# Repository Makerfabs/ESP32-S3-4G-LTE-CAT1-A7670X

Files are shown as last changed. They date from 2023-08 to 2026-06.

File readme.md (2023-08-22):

# ESP32-S3-Parallel-TFT-with-Touch-1.9inch

```
/* 
    Version:      V1.0
    Author:       Vincent
    Create Date:  2023/8/22
*/
```

# Makerfabs

[Makerfabs home page](https://www.makerfabs.com/)

[Makerfabs Wiki](https://wiki.makerfabs.com/)

## Intruduce

Product Link:[]()

Wiki Link : []()

## Features

- Controller: ESP32-S3
- Wireless: WiFi& Bluetooth 5.0
- Arduino support
- MicroPython support: Yes
- Operation temperature: -40℃ to +85℃
- USB: USB Native, Type-C
- Power Supply: USB Type-C 5.0V(4.0V~5.25V); 3.7V Lipo battery

# Usage

All supporting information, such as the AT instructions and other official documents are in the A76XX Manual.zip.

## Complier Option

- Use type-c use cable connect USB-TTL to PC.
- Select "ESP32-S3 DEV Module"
- Select PSRAM "OPI PSRAM"

## Example

at_command_demo.ino

Serial port transparent transmission demo.
Can be used to test AT Commands.

## AT Commands

### AT+CSQ

Query signal quality

```
AT+CSQ
+CSQ: 28,99

OK

```

### AT+SIMCOMATI

Example Query module information

```
AT+SIMCOMATI
Manufacturer: INCORPORATED
Model: A7670SA-FASE
Revision: A011B04A7670M7_F
A7670M7_B04V02_220927
QCN:
IMEI: 869731059057646
MEID:
+GCAP: +CGSM,+FCLASS,+DS
DeviceInfo:

OK

```

### AT+COPS

Operator selection

```
AT+COPS?
+COPS: 0,2,"46000",7

OK

```

### AT+CICCID

Read ICCID from SIM card

```
AT+CICCID
+ICCID: 898607E0102250030751

OK

```

### AT+CBC

Read the voltage value of the power supply

```
AT+CBC
+CBC: 4.167V

OK

```

## TTS Test

```
AT+CTTSPARAM=? 
AT+CTTSPARAM=1,3,0,1,1 
AT+CTTSPARAM?
AT+CTTS=1,"6B228FCE4F7F75288BED97F3540862107CFB7EDF" 
AT+CTTS=2,"Hi, Makerfabs"

```

## LBS Test

```
AT+CLBS=? 
AT+SIMCOMATI
AT+SIMEI=xxxxx 
AT+CLBS=2 
AT+CLBS=1
```

## Make a call

```
ATD<phone_number>;
AT+COUTGAIN=?
AT+COUTGAIN=5
AT+CHUP 
```
## TCP test

```
AT+CIPMODE=1
AT+NETOPEN
AT+CIPOPEN=0,"TCP","122.114.122.174",39348
Hi,Makerfabs
AT+CIPCLOSE=0
AT+NETCLOSE
```
## LBS Test

```
AT+CLBS=? 
AT+SIMCOMATI
AT+SIMEI=xxxxx 
AT+CLBS=2 
AT+CLBS=1
```
## HTTP Test

```
AT+HTTPINIT
AT+HTTPPARA="URL","http:www.makerfabs.com"
AT+HTTPACTION=0
AT+HTTPHEAD
AT+HTTPREAD=0,500
AT+HTTPTERM
```

## MQTT Test

```
AT+CMQTTSTART
AT+CMQTTACCQ=0,"client test0"
AT+CMQTTWILLTOPIC=0,10
AT+CMQTTWILLMSG=0,6,1
AT+CMQTTCONNECT=0,"tcp://test.mosquitto.org:1883",60,1
AT+CMQTTSUB=0,9,1
AT+CMQTTTOPIC=0,9
AT+CMQTTPAYLOAD=0,60
```

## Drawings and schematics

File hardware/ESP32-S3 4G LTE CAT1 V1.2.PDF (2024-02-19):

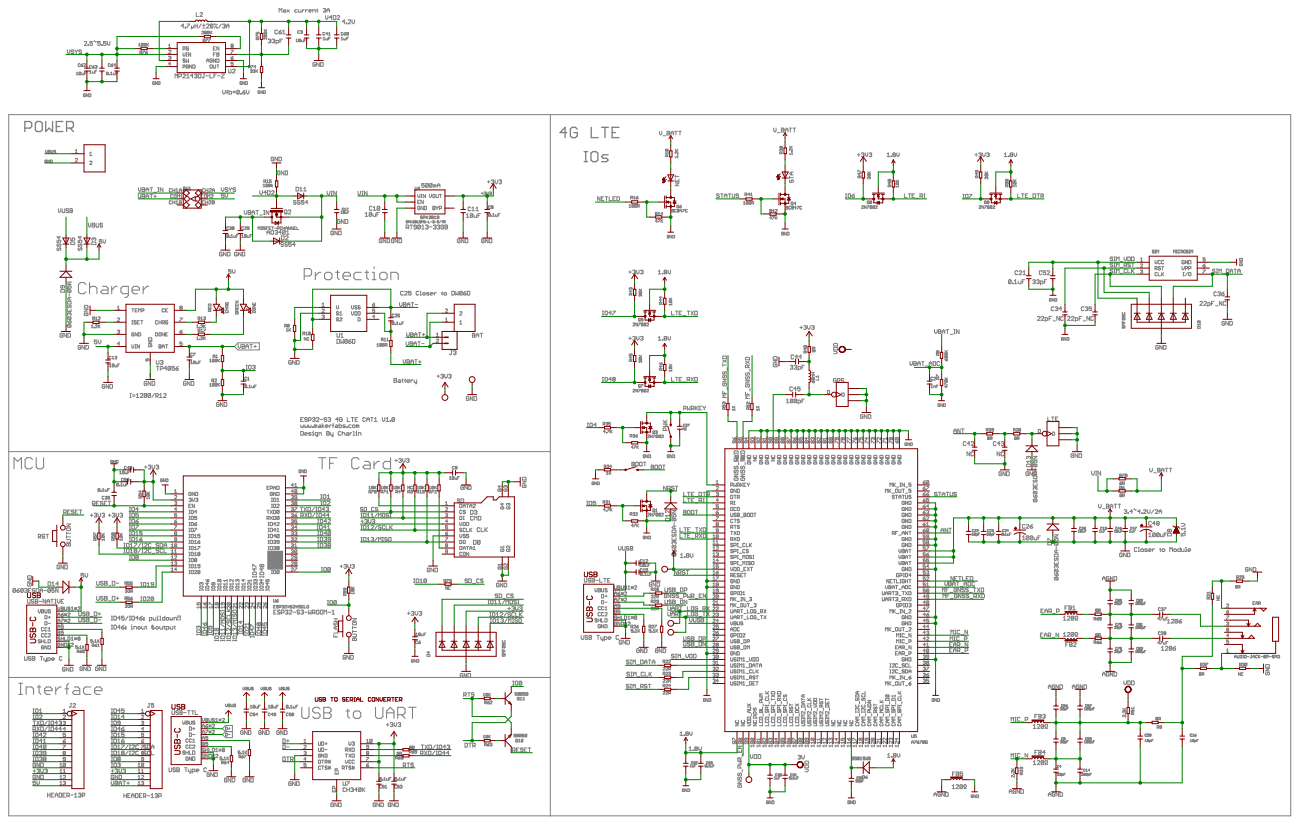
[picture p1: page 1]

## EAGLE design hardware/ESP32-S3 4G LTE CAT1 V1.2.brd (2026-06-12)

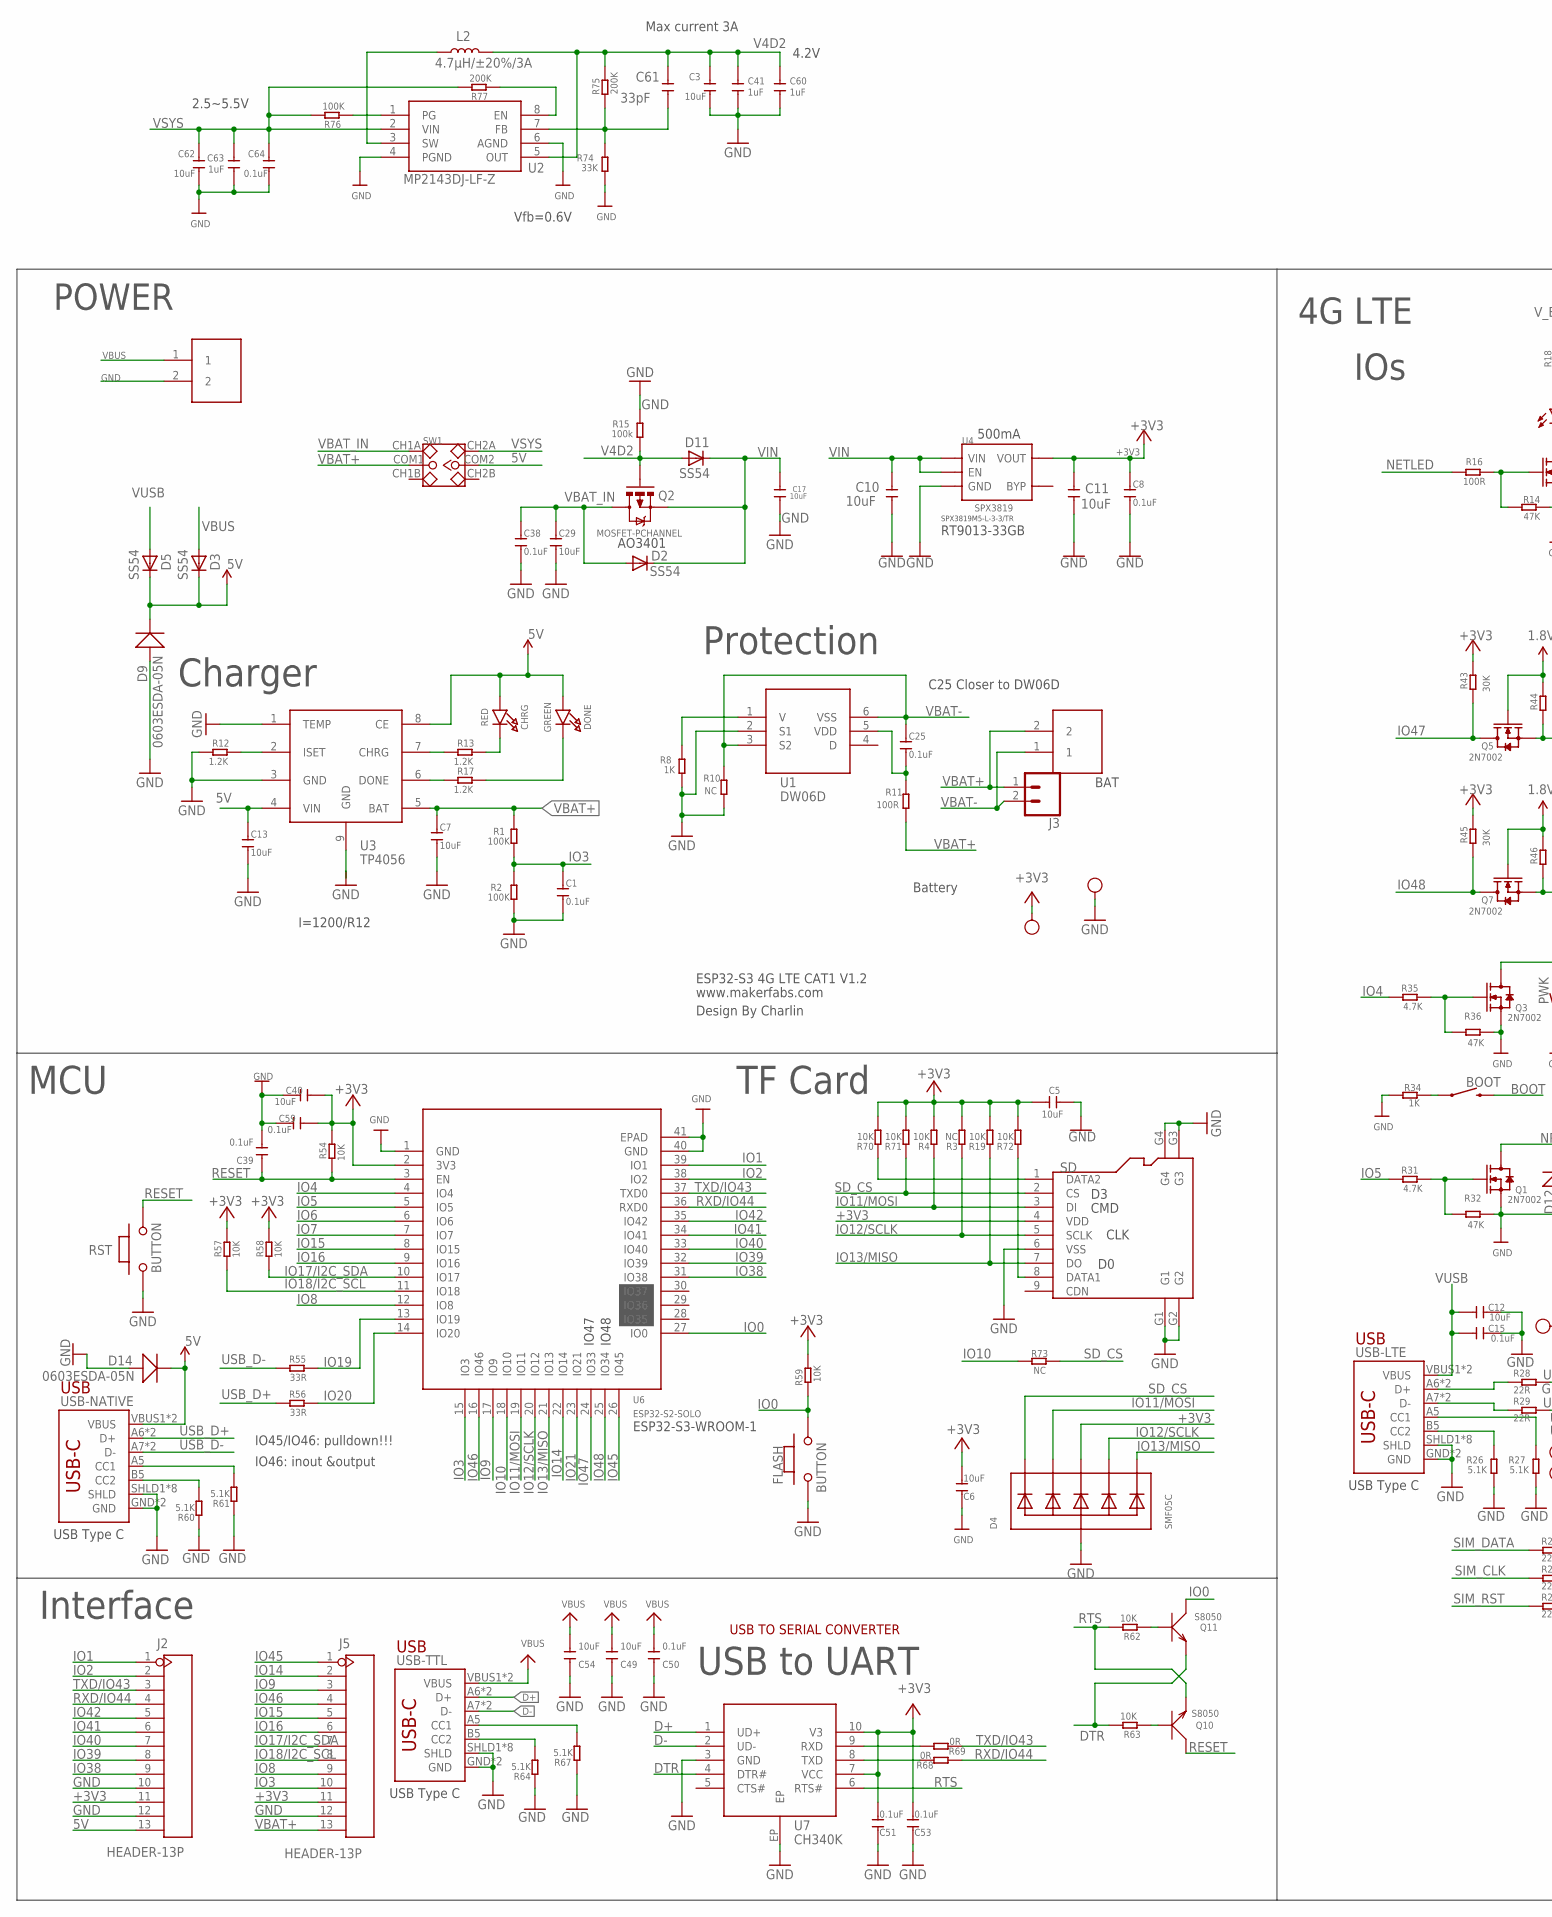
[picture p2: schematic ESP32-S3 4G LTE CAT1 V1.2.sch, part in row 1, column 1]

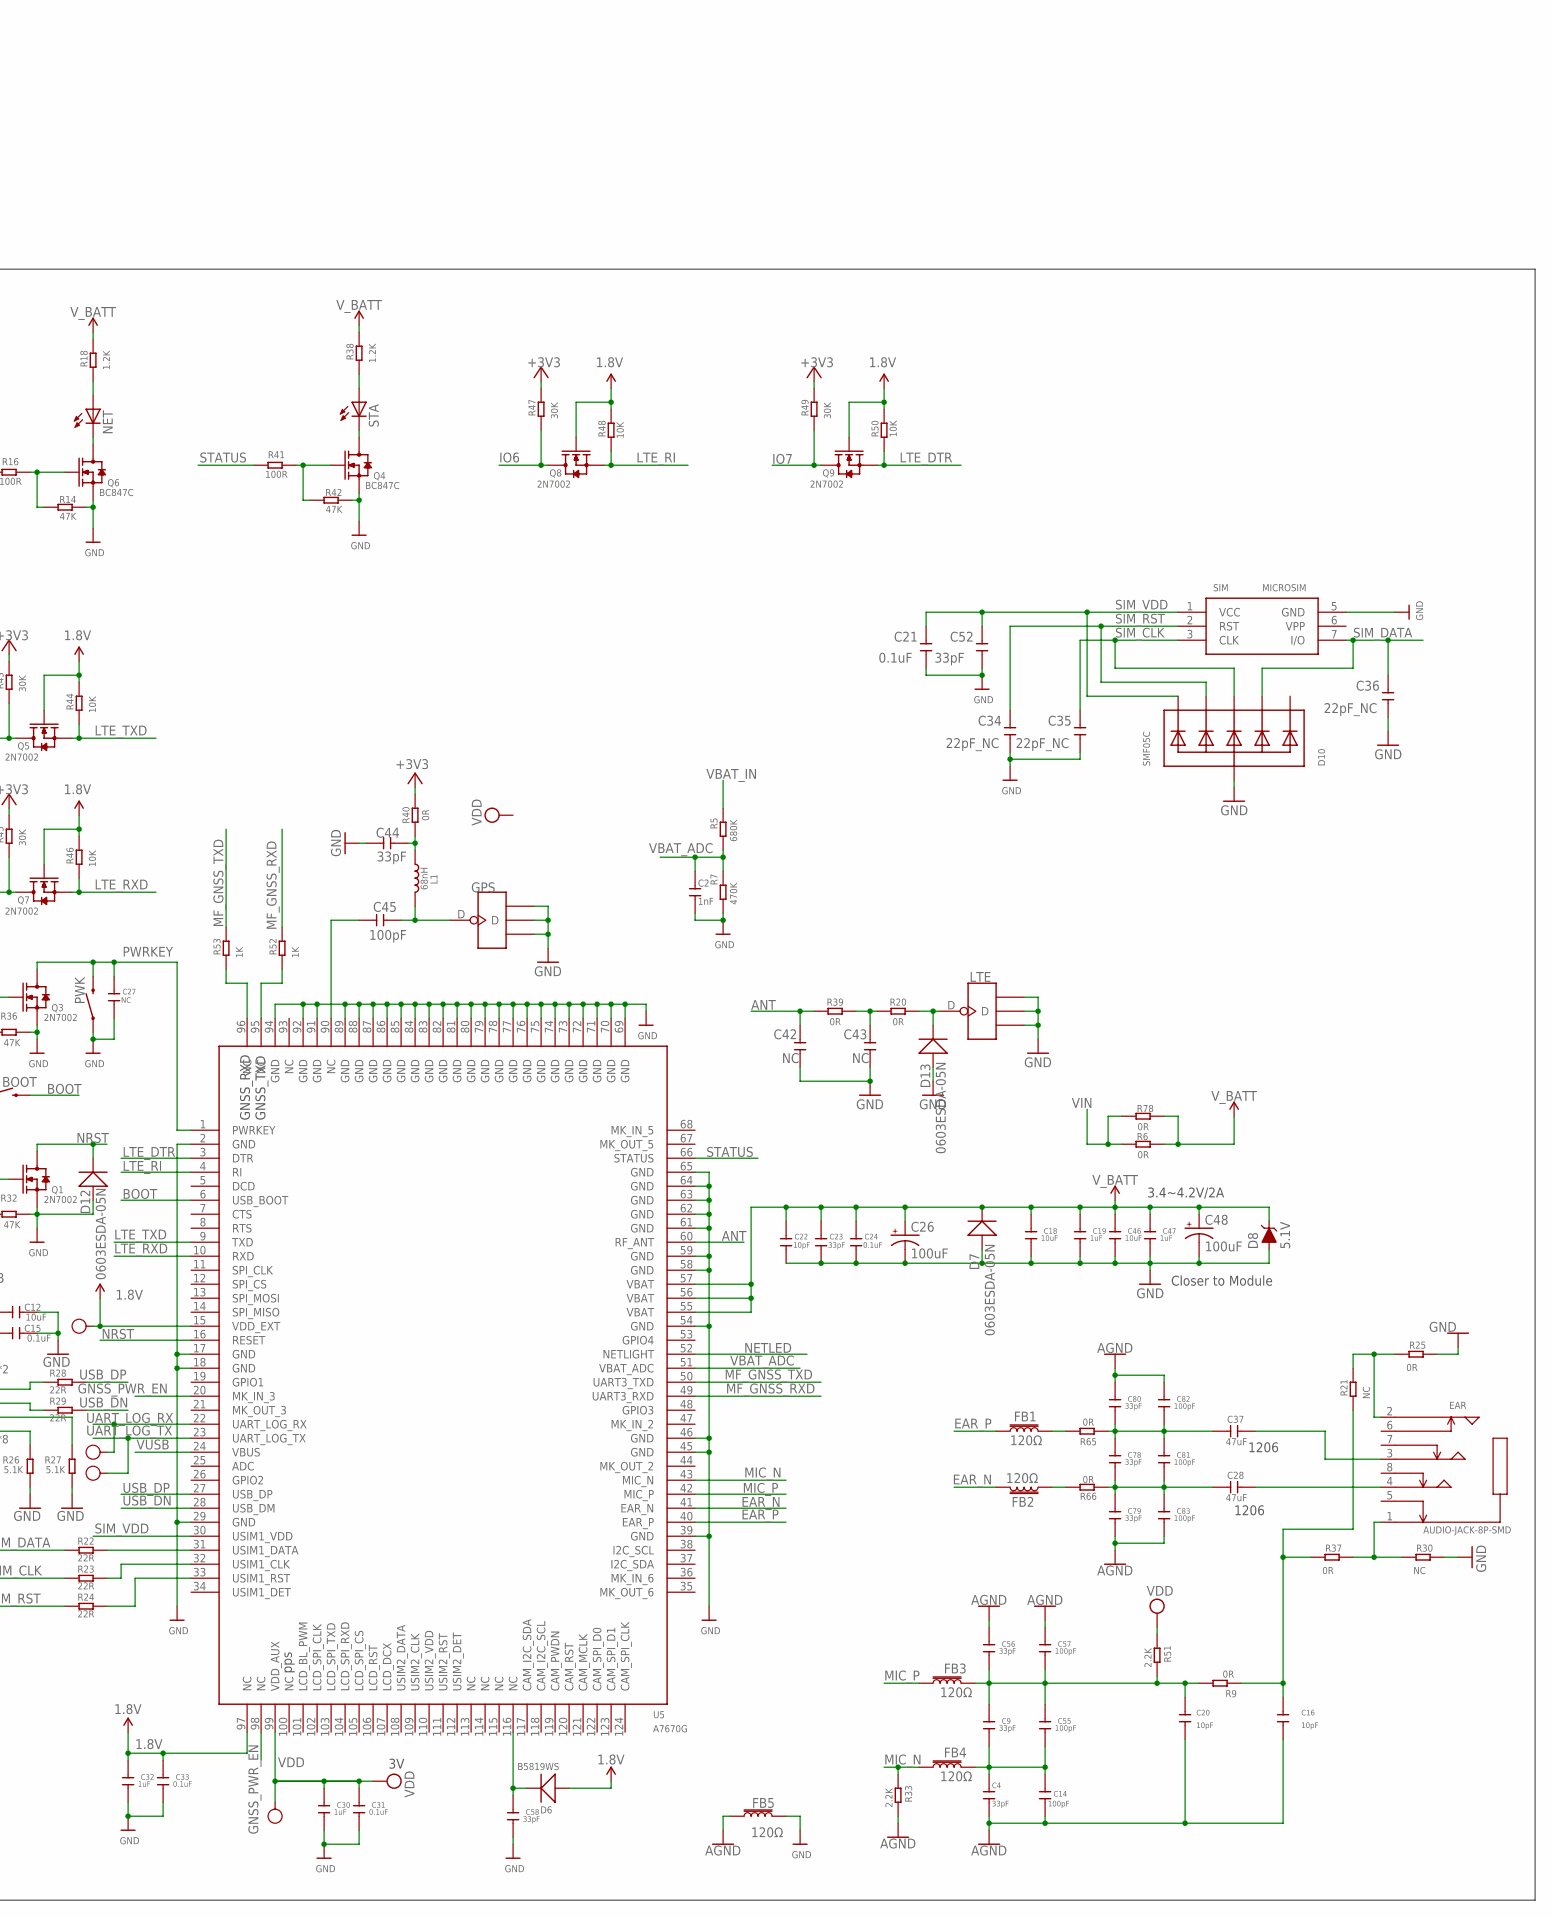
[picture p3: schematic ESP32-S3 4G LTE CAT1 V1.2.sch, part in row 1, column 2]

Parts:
1V8, 3V, 3V3: TEST-POINT'4545'; TP-D45MIL; PARTNO DNP
BAT: PH2.0-2P-90-DIP
BOOT: MOMENTARY-SWITCH-SPST-SMD-6.0X3.5MM; TACTILE_SWITCH_SMD_6.0X3.5MM
C1, C8, C15, C21, C24, C25, C31, C33, C38, C64: 0.1uF; 0603
C2: 1nF; 0603
C3, C7, C10, C11, C12, C13, C17, C18, C29, C46, C62: 10uF; 0603
C4, C9, C23, C44, C52, C56, C58, C61, C78, C79, C80: 33pF; 0603
C5, C6, C40, C49, C54: 10uF; DISCRETE_C0603
C14, C45, C55, C57, C81, C82, C83: 100pF; 0603
C16, C20, C22: 10pF; 0603
C19, C30, C32, C41, C47, C60, C63: 1uF; 0603
C26, C48: 100uF; EIA3528
C27, C42, C43: NC; 0603
C28, C37: 47uF; DISCRETE_C1206
C34, C35, C36: 22pF_NC; 0603
C39, C50, C51, C53, C59: 0.1uF; DISCRETE_C0603
CHRG: RED; CHIPLED_0805_NOOUTLINE
D2, D3, D5, D11: SS54; DO-214AC
D4, D10: SMF05C; SOT363
D6: B5819WS; SOD323
D7, D9, D12, D13, D14: 0603ESDA-05N; DISCRETE_SOD523
D8: 5.1V; SOD-323
DONE: GREEN; CHIPLED_0805_NOOUTLINE
EAR: AUDIO-JACK-8P-SMD; AUDIO8P-SMD-3.5-14.5X6.1X4.0MM
FB1, FB2, FB3, FB4, FB5: 120Ω; 0603
FLASH: BUTTON; 157SW
GND: TEST-POINT'4545'; TP-D45MIL; PARTNO DNP
GPS: ANTENNA-U-FL; 4P-U-FL
J1: PH2.0-2P-90-DIP
J2, J5: HEADER-13P; 13P-2.54
J3: CONN_02LOCK; 1X02_LOCK
L1: 68nH; L0603
L2: 4.7µH/±20%/3A; SRN6045
LTE: ANTENNA-U-FL; 4P-U-FL
NET: NET; CHIP-LED0805
PWK: MOMENTARY-SWITCH-SPST-SMD-6.0X3.5MM; TACTILE_SWITCH_SMD_6.0X3.5MM
Q1, Q3, Q5, Q7, Q8, Q9: 2N7002; SOT23
Q2: MOSFET-PCHANNEL; SOT23-3
Q4, Q6: BC847C; SOT23
Q10, Q11: S8050; SOT23
R1, R2, R76: 100K; R0603
R3: NC; DISCRETE_R0603
R4, R19, R70, R71, R72: 10K; DISCRETE_R0603
R5: 680K; R0603
R6, R9, R20, R25, R37, R39, R40, R65, R66, R68, R69, R78: 0R; R0603
R7: 470K; R0603
R8, R34, R52, R53: 1K; R0603
R10, R21, R30, R73: NC; R0603
R11, R16, R41: 100R; R0603
R12, R13, R17, R18, R38: 1.2K; R0603
R14, R32, R36, R42: 47K; R0603
R15: 100k; R0603
R22, R23, R24, R28, R29: 22R; R0603
R26, R27: 5.1K; R0603
R31, R35: 4.7K; R0603
R33, R51: 2.2K; R0603
R43, R45, R47, R49: 30K; R0603
R44, R46, R48, R50, R54, R57, R58, R59, R62, R63: 10K; R0603
R55, R56: 33R; R0603
R60, R61, R64, R67: 5.1K; DISCRETE_R0603
R74: 33K; R0603
R75, R77: 200K; R0603
RST: BUTTON; 157SW
RX: TEST-POINT'4545'; TP-D45MIL; PARTNO DNP
SD: HOLDER-MICROSD-9P; 9P-SMD-W/-RING
SIM: MICROSIM
STA: NET; CHIP-LED0805
SW1: SWITCH-2CH-6P; 6P-2CH-2.54-7.6X3.0
TX: TEST-POINT'4545'; TP-D45MIL; PARTNO DNP
U1: DW06D; SOT-23-6
U2: MP2143DJ-LF-Z; TSOT23-8
U3: TP4056; SOP8-1.27P
U4: SPX3819; SOT23-5
U5: A7670G
U6: ESP32­S2­SOLO; ESP32-­S2-­SOLO
U7: CH340K; ESOP-10-EP-150MIL
USB-LTE: USB_C5; USB-C-16P-5
USB-NATIVE: USB_C5; USB-C-16P-5
USB-TTL: USB_C5; USB-C-16P-5

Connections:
1.8V: 1V8.T, C32.2, C33.2, D6.+, Q5.1 (G), Q7.1 (G), Q8.1 (G), Q9.1 (G), R44.2, R46.2, R48.2, R50.2, U5.15 (VDD_EXT), U5.97 (NC)
5V: C13.1, CHRG.A, D3.C, D5.C, D9.-, D14.-, DONE.A, J2.13, SW1.COM2, U3.4 (VIN), U3.8 (CE), USB-NATIVE.VBUS1 (VBUS), USB-NATIVE.VBUS2 (VBUS)
+3V3: 3V3.T, C5.2, C6.2, C8.1, C11.2, C40.2, C51.2, C53.2, C59.2, D4.4 (C3), J2.11, J5.11, R3.2, R4.2, R19.2, R40.2, R43.2, R45.2, R47.2, R49.2, R54.2, R57.2, R58.2, R59.2, R70.2, R71.2, R72.2, SD.4 (VDD), U4.5 (VOUT), U6.2 (3V3), U7.7 (VCC), U7.10 (V3)
AGND: C4.1, C14.1, C16.1, C20.1, C56.2, C57.2, C79.1, C80.2, C82.2, C83.1, FB5.1, R33.2
ANT: C42.2, R39.1, U5.60 (RF_ANT)
BOOT: BOOT.2, U5.6 (USB_BOOT)
D+: U7.1 (UD+), USB-TTL.A6 (D+), USB-TTL.B6 (D+)
D-: U7.2 (UD-), USB-TTL.A7 (D-), USB-TTL.B7 (D-)
DONE: R17.2, U3.6 (DONE)
DTR: Q11.2 (E), R63.2, U7.4 (DTR#)
EAR_N: FB2.2, U5.41 (EAR_N)
EAR_P: FB1.1, U5.40 (EAR_P)
GND: C1.2, C2.2, C3.1, C5.1, C6.1, C7.2, C8.2, C10.1, C11.1, C12.2, C13.2, C15.2, C17.1, C18.1, C19.1, C21.1, C22.1, C23.1, C24.1, C26.C (-), C27.1, C29.2, C30.1, C31.1, C32.1, C33.1, C34.1, C35.1, C36.1, C38.2, C39.2, C40.1, C41.1, C42.1, C43.1, C44.2, C46.1, C47.1, C48.C (-), C49.1, C50.1, C51.1, C52.1, C53.1, C54.1, C58.1, C59.1, C60.1, C62.1, C63.1, C64.1, D4.2 (A), D7.+, D8.A, D9.+, D10.2 (A), D12.+, D13.+, D14.+, FB5.2, FLASH.1, GND.T, GPS.GND1, GPS.GND2, GPS.GND3, J1.2, J2.10, J2.12, J5.12, LTE.GND1, LTE.GND2, LTE.GND3, PWK.1, Q1.2 (S), Q3.2 (S), Q4.2 (S), Q6.2 (S), R2.1, R7.1, R8.1, R10.1, R12.2, R14.1, R15.2, R25.2, R26.1, R27.1, R30.2, R32.1, R34.2, R36.1, R42.1, R60.1, R61.1, R64.1, R67.1, R74.1, RST.1, SD.6 (VSS), SD.G1, SD.G2, SD.G3, SD.G4, SIM.5 (GND), U1.2 (S1), U2.4 (PGND), U2.6 (AGND), U3.1 (TEMP), U3.3 (GND), U3.9 (GND), U4.2 (GND), U5.2 (GND), U5.17 (GND), U5.18 (GND), U5.29 (GND), U5.39 (GND), U5.45 (GND), U5.46 (GND), U5.54 (GND), U5.58 (GND), U5.59 (GND), U5.61 (GND), U5.62 (GND), U5.63 (GND), U5.64 (GND), U5.65 (GND), U5.69 (GND), U5.70 (GND), U5.71 (GND), U5.72 (GND), U5.73 (GND), U5.74 (GND), U5.75 (GND), U5.76 (GND), U5.77 (GND), U5.78 (GND), U5.79 (GND), U5.80 (GND), U5.81 (GND), U5.82 (GND), U5.83 (GND), U5.84 (GND), U5.85 (GND), U5.86 (GND), U5.87 (GND), U5.88 (GND), U5.89 (GND), U5.91 (GND), U5.92 (GND), U5.94 (GND), U6.1 (GND), U6.40 (GND), U6.41 (EPAD), U7.3 (GND), U7.EP, USB-LTE.GND, USB-LTE.GND2 (GND), USB-LTE.SHLD1 (SHLD), USB-LTE.SHLD2 (SHLD), USB-LTE.SHLD3 (SHLD), USB-LTE.SHLD4 (SHLD), USB-LTE.SHLD5 (SHLD), USB-LTE.SHLD6 (SHLD), USB-LTE.SHLD7 (SHLD), USB-LTE.SHLD8 (SHLD), USB-NATIVE.GND, USB-NATIVE.GND2 (GND), USB-NATIVE.SHLD1 (SHLD), USB-NATIVE.SHLD2 (SHLD), USB-NATIVE.SHLD3 (SHLD), USB-NATIVE.SHLD4 (SHLD), USB-NATIVE.SHLD5 (SHLD), USB-NATIVE.SHLD6 (SHLD), USB-NATIVE.SHLD7 (SHLD), USB-NATIVE.SHLD8 (SHLD), USB-TTL.GND, USB-TTL.GND2 (GND), USB-TTL.SHLD1 (SHLD), USB-TTL.SHLD2 (SHLD), USB-TTL.SHLD3 (SHLD), USB-TTL.SHLD4 (SHLD), USB-TTL.SHLD5 (SHLD), USB-TTL.SHLD6 (SHLD), USB-TTL.SHLD7 (SHLD), USB-TTL.SHLD8 (SHLD)
GNSS_PWR_EN: U5.20 (MK_IN_3), U5.98 (NC)
IO0: FLASH.2, Q11.3 (C), R59.1, U6.27 (IO0)
IO1: J2.1, U6.39 (IO1)
IO2: J2.2, U6.38 (IO2)
IO3: C1.1, J5.10, R1.1, R2.2, U6.15 (IO3)
IO4: R35.2, U6.4 (IO4)
IO5: R31.2, U6.5 (IO5)
IO6: Q8.3 (D), R47.1, U6.6 (IO6)
IO7: Q9.3 (D), R49.1, U6.7 (IO7)
IO8: J5.9, U6.12 (IO8)
IO9: J5.3, U6.17 (IO9)
IO10: R73.1, U6.18 (IO10)
IO11/MOSI: D4.3 (C2), R4.1, SD.3 (DI), U6.19 (IO11)
IO12/SCLK: D4.5 (C4), R3.1, SD.5 (SCLK), U6.20 (IO12)
IO13/MISO: D4.6 (C5), R19.1, SD.7 (DO), U6.21 (IO13)
IO14: J5.2, U6.22 (IO14)
IO15: J5.5, U6.8 (IO15)
IO16: J5.6, U6.9 (IO16)
IO17/I2C_SDA: J5.7, R58.1, U6.10 (IO17)
IO18/I2C_SCL: J5.8, R57.1, U6.11 (IO18)
IO19: R55.2, U6.13 (IO19)
IO20: R56.2, U6.14 (IO20)
IO21: U6.23 (IO21)
IO38: J2.9, U6.31 (IO38)
IO39: J2.8, U6.32 (IO39)
IO40: J2.7, U6.33 (IO40)
IO41: J2.6, U6.34 (IO41)
IO42: J2.5, U6.35 (IO42)
IO45: J5.1, U6.26 (IO45)
IO46: J5.4, U6.16 (IO46)
IO47: Q5.3 (D), R43.1, U6.24 (IO33)
IO48: Q7.3 (D), R45.1, U6.25 (IO34)
ISET: R12.1, U3.2 (ISET)
LTE_DTR: Q9.2 (S), R50.1, U5.3 (DTR)
LTE_RI: Q8.2 (S), R48.1, U5.4 (RI)
LTE_RXD: Q7.2 (S), R46.1, U5.10 (RXD)
LTE_TXD: Q5.2 (S), R44.1, U5.9 (TXD)
MF_GNSS_RXD: R52.2, U5.49 (UART3_RXD)
MF_GNSS_TXD: R53.2, U5.50 (UART3_TXD)
MIC_N: FB4.1, R33.1, U5.43 (MIC_N)
MIC_P: FB3.1, U5.42 (MIC_P)
unnamed: NET.C, Q6.3 (D)
unnamed: CHRG.C, R13.1
unnamed: D13.-, LTE.D, R20.2
unnamed: Q4.1 (G), R41.1, R42.2
unnamed: Q6.1 (G), R14.2, R16.1
unnamed: NET.A, R18.1
unnamed: R70.1, SD.1 (DATA2)
unnamed: BOOT.1, R34.1
unnamed: C25.2, R11.2, U1.5 (VDD)
unnamed: R8.2, U1.1 (V)
unnamed: DONE.C, R17.1
unnamed: R13.2, U3.7 (CHRG)
unnamed: C16.2, R9.1, R21.1, R37.1
unnamed: C9.2, C20.2, C55.2, C56.1, C57.1, FB3.2, R9.2, R51.2
unnamed: EAR.2, R21.2, R25.1
unnamed: FB2.1, R66.2
unnamed: R72.1, SD.8 (DATA1)
unnamed: C58.2, D6.-, U5.116 (NC)
unnamed: EAR.1, R30.1, R37.2
unnamed: C28.1, C78.1, C79.2, C81.1, C83.2, R66.1
unnamed: R22.1, U5.31 (USIM1_DATA)
unnamed: R23.1, U5.32 (USIM1_CLK)
unnamed: R24.1, U5.33 (USIM1_RST)
unnamed: C4.2, C9.1, C14.2, C55.1, FB4.2
unnamed: L2.1, U2.3 (SW)
unnamed: R27.2, USB-LTE.A5 (CC1)
unnamed: R26.2, USB-LTE.B5 (CC2)
unnamed: R38.1, STA.A
unnamed: Q4.3 (D), STA.C
unnamed: C37.1, C78.2, C80.1, C81.2, C82.1, R65.1
unnamed: R28.2, USB-LTE.A6 (D+), USB-LTE.B6 (D+)
unnamed: R29.2, USB-LTE.A7 (D-), USB-LTE.B7 (D-)
unnamed: Q1.1 (G), R31.1, R32.2
unnamed: C45.2, U5.90 (NC)
unnamed: C28.2, EAR.4
unnamed: R52.1, U5.95 (NC)
unnamed: R53.1, U5.96 (NC)
unnamed: C61.1, R74.2, R75.1, U2.7 (FB)
unnamed: R76.1, U2.1 (PG)
unnamed: R61.2, USB-NATIVE.A5 (CC1)
unnamed: R60.2, USB-NATIVE.B5 (CC2)
unnamed: Q3.1 (G), R35.1, R36.2
unnamed: Q10.1 (B), R63.1
unnamed: Q11.1 (B), R62.1
unnamed: R67.2, USB-TTL.A5 (CC1)
unnamed: R64.2, USB-TTL.B5 (CC2)
unnamed: R69.2, U7.9 (RXD)
unnamed: R68.2, U7.8 (TXD)
unnamed: R77.1, U2.8 (EN)
unnamed: FB1.2, R65.2
unnamed: C37.2, EAR.3
unnamed: C43.2, R20.1, R39.2
unnamed: C44.1, L1.1, R40.1
unnamed: C45.1, GPS.D, L1.2
NETLED: R16.2, U5.52 (NETLIGHT)
NRST: D12.-, Q1.3 (D), U5.16 (RESET)
PWRKEY: C27.2, PWK.2, Q3.3 (D), U5.1 (PWRKEY)
RESET: C39.1, Q10.3 (C), R54.1, RST.2, U6.3 (EN)
RTS: Q10.2 (E), R62.2, U7.6 (RTS#)
RXD/IO44: J2.4, R68.1, U6.36 (RXD0)
SD_CS: D4.1 (C1), R71.1, R73.2, SD.2 (CS)
SIM_CLK: C35.2, D10.4 (C3), R23.2, SIM.3 (CLK)
SIM_DATA: C36.2, D10.3 (C2), R22.2, SIM.7 (I/O)
SIM_RST: C34.2, D10.5 (C4), R24.2, SIM.2 (RST)
SIM_VDD: C21.2, C52.2, D10.6 (C5), SIM.1 (VCC), U5.30 (USIM1_VDD)
STATUS: R41.2, U5.66 (STATUS)
TXD/IO43: J2.3, R69.1, U6.37 (TXD0)
UART_LOG_RX: RX.T, U5.22 (UART_LOG_RX)
UART_LOG_TX: TX.T, U5.23 (UART_LOG_TX)
USB_D+: R56.1, USB-NATIVE.A6 (D+), USB-NATIVE.B6 (D+)
USB_D-: R55.1, USB-NATIVE.A7 (D-), USB-NATIVE.B7 (D-)
USB_DN: R29.1, U5.28 (USB_DM)
USB_DP: R28.1, U5.27 (USB_DP)
V4D2: C3.2, C41.2, C60.2, C61.2, D11.A, L2.2, Q2.1 (G), R15.1, R75.2, U2.5 (OUT)
VBAT+: BAT.2, C7.1, J3.1, J5.13, R1.2, R11.1, SW1.COM1, U3.5 (BAT)
VBAT-: BAT.1, C25.1, J3.2, R10.2, U1.3 (S2), U1.6 (VSS)
VBAT_ADC: C2.1, R5.1, R7.2, U5.51 (VBAT_ADC)
VBAT_IN: C29.1, C38.1, D2.A, Q2.3 (D), R5.2, SW1.CH1A
VBUS: C49.2, C50.2, C54.2, D3.A, J1.1, USB-TTL.VBUS1 (VBUS), USB-TTL.VBUS2 (VBUS)
VDD: 3V.T, C30.2, C31.2, R51.1, U5.99 (VDD_AUX)
VIN: C10.2, C17.2, D2.C, D11.C, Q2.2 (S), R6.2, R78.2, U4.1 (VIN), U4.3 (EN)
VSYS: C62.2, C63.2, C64.2, R76.2, R77.2, SW1.CH2A, U2.2 (VIN)
VUSB: C12.1, C15.1, D5.A, U5.24 (VBUS), USB-LTE.VBUS1 (VBUS), USB-LTE.VBUS2 (VBUS)
V_BATT: C18.2, C19.2, C22.2, C23.2, C24.2, C26.A (+), C46.2, C47.2, C48.A (+), D7.-, D8.C, R6.1, R18.2, R38.2, R78.1, U5.55 (VBAT), U5.56 (VBAT), U5.57 (VBAT)

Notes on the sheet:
ESP32-S3 4G LTE CAT1 V1.2
www.makerfabs.com
IOs
Battery
C25 Closer to DW06D
Protection
BAT
I=1200/R12
Charger
500mA
POWER
AO3401
SPX3819M5-L-3-3/TR
RT9013-33GB
USB
USB Type C
Closer to Module
3.4~4.2V/2A
GNSS_TXD
GNSS_RXD
1206
IO45/IO46: pulldown!!!
IO46: inout &output
MCU
ESP32-S3-WROOM-1
IO47
IO48
USB TO SERIAL CONVERTER
USB to UART
Design By Charlin
TF Card
CMD
CLK
4G LTE
Interface
pps
4.2V
Max current 3A
Vfb=0.6V
2.5~5.5V

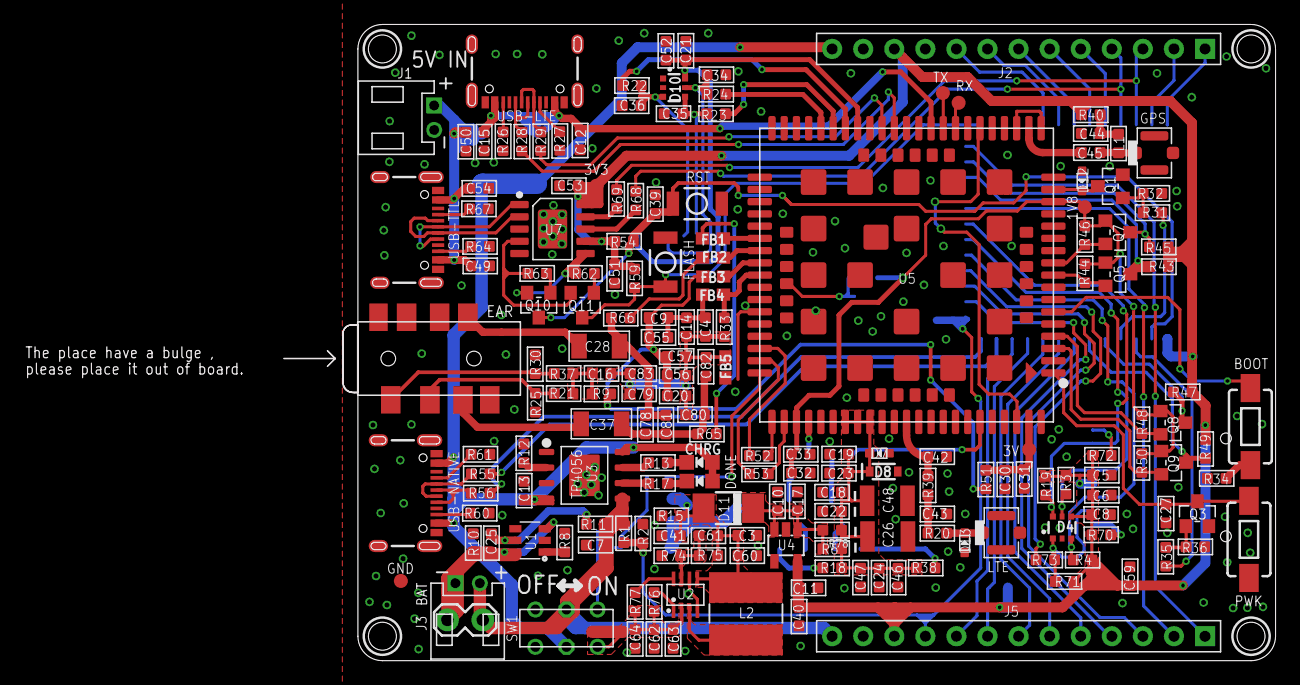
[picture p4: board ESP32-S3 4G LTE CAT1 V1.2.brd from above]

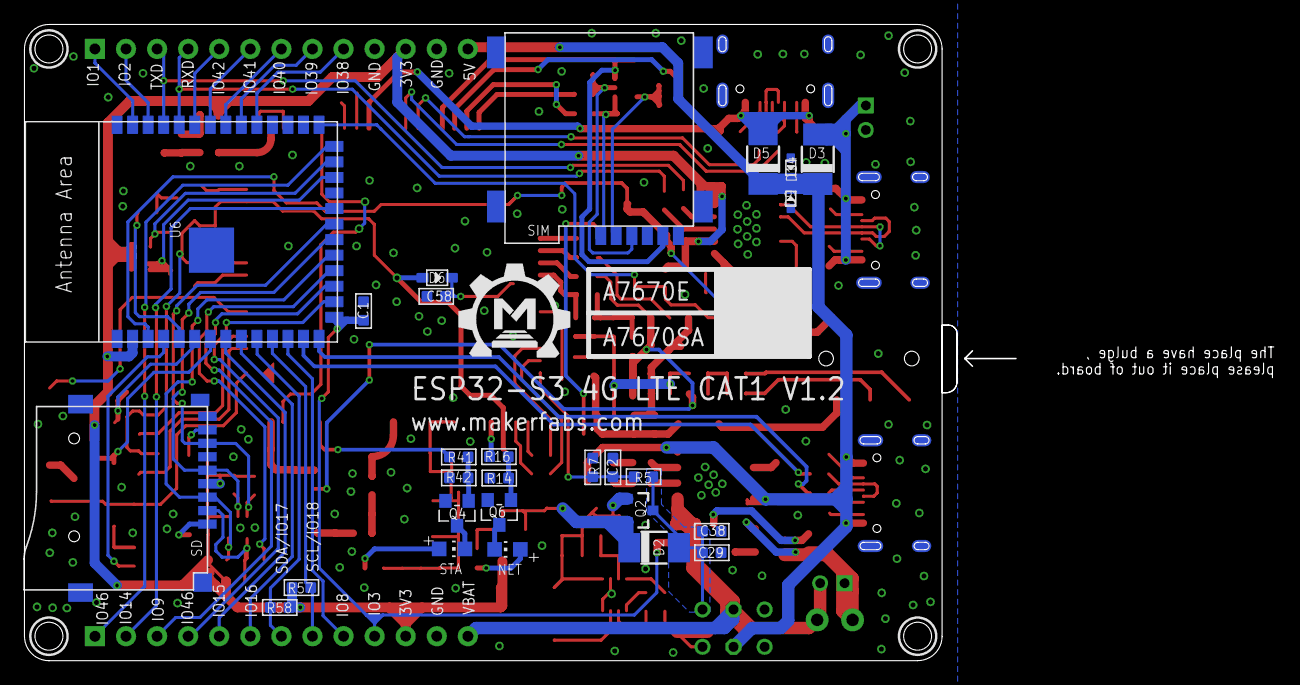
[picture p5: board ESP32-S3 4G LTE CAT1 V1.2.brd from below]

Board: 2 copper layers, 81.0 x 52.0 mm, 215 parts (28 on the bottom side), 137 nets.

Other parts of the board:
U$1: MAKERFABS_0.3

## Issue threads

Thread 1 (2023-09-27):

minimum battery mah?

abuvanth, 2023-09-27:
what is the minimum mah of the battery?

abuvanth, 2023-09-27:
what will happen if USB power and battery power connected same time?

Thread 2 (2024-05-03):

Website down

ruben148, 2024-05-03:
Your website is down right now. When will it be available again?
If it won't be in the near future, can you please send me a photo with the pinout of the Makerfabs A7670X module (ESP32S3)? www.makerfabs.com/esp32s3-4g-lte.html - this was the link to the product.

Closed 2024-05-04.

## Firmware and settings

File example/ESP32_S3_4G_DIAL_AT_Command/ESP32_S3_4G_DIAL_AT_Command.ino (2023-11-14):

#include <Arduino.h>

HardwareSerial mySerial2(2);

#define DEBUG true



#define IO_RXD2 47
#define IO_TXD2 48



// change this to match your SD shield or module;
// ESP32-S3 4G LTE: pin 10
const int PIN_SD_SELECT = 10;


#define IO_GSM_PWRKEY 4
#define IO_GSM_RST    5

unsigned long currentTime;


String sendData(String command, const int timeout, boolean debug)
{
  String response = "";
  mySerial2.println(command);
  long int time = millis();
  while ( (time + timeout) > millis())
  {
    while (mySerial2.available())
    {
      char c = mySerial2.read();
      response += c;
    }
  }
  if (debug)
  {
    USBSerial.print(response);
  }
  return response;
}


void setup() {
  // put your setup code here, to run once:
  USBSerial.begin(115200);
  USBSerial.print(F("Hello! ESP32-S3 AT command V1.0 Test"));
  mySerial2.begin(115200,SERIAL_8N1, IO_RXD2, IO_TXD2);
  pinMode(IO_GSM_RST, OUTPUT);
  digitalWrite(IO_GSM_RST, LOW);
  
  pinMode(IO_GSM_PWRKEY, OUTPUT);
  digitalWrite(IO_GSM_PWRKEY, HIGH);
  delay(3000);
  digitalWrite(IO_GSM_PWRKEY, LOW);
  
  USBSerial.println("ESP32-S3 4G LTE CAT1 Test Start!");
  delay(2000);
  delay(2000);
  USBSerial.println("Wait a few minutes for 4G star");
  delay(3000);
  sendData("AT", 1000, DEBUG);
  sendData("AT+CICCID", 1000, DEBUG);
  sendData("AT+SIMCOMATI", 1000, DEBUG);
  sendData("AT+COPS?", 1000, DEBUG); 
  sendData("AT+GMR", 1000, DEBUG); 

  #if 0
  //Get GNSS location  //GPS test
  sendData("AT+CGNSSPWR=1", 1000, DEBUG);// turn the GPS on //must wait about 10s for GPS on
  delay(12000); //Go on after shows +CGNSSPWR: READY!
  
  sendData("AT+CGNSSIPR=9600", 1000, DEBUG);//
  sendData("AT+CGNSSTST=1", 1000, DEBUG);
  sendData("AT+CGNSSINFO", 1000, DEBUG);//get GPS infomation
  #endif

#if 0
//  delay(2000);
//  delay(2000);
  delay(1000);
  //sendData("AT", 1000, DEBUG);
  delay(1000);
  sendData("AT", 1000, DEBUG);
  delay(1000);
  sendData("AT+SIMCOMATI", 1000, DEBUG);
  delay(1000);
  sendData("AT+CICCID", 1000, DEBUG);
  sendData("AT+CNUM", 1000, DEBUG);
  sendData("AT+COPS?", 1000, DEBUG);    
  sendData("AT+CPSI?", 1000, DEBUG);
  sendData("AT+CNMP?", 1000, DEBUG);
  
  //Http test
  sendData("AT+HTTPINIT", 1000, DEBUG);
  sendData("AT+HTTPPARA=\"URL\",\"https://ss0.bdstatic.com/5aV1bjqh_Q23odCf/static/mancard/css/card_min_dee38e45.css\"", 1000, DEBUG);
  sendData("AT+HTTPACTION=0", 1000, DEBUG);
  sendData("AT+CSQ", 1000, DEBUG);
  sendData("AT+HTTPHEAD", 1000, DEBUG);
  sendData("AT+HTTPREAD=0,500", 1000, DEBUG);
  sendData("AT+HTTPTERM", 1000, DEBUG);
#endif

//Make a call
#if 1
  delay(1000);
  //sendData("AT", 1000, DEBUG);
  delay(1000);
  sendData("AT", 1000, DEBUG);
  delay(1000);
  sendData("AT+SIMCOMATI", 1000, DEBUG);
  delay(1000);
  sendData("AT+CICCID", 1000, DEBUG);
  sendData("AT+CNUM", 1000, DEBUG);
  sendData("AT+COPS?", 1000, DEBUG);    
  sendData("AT+CPSI?", 1000, DEBUG);
  sendData("AT+CNMP?", 1000, DEBUG);
  sendData("ATD10086;", 1000, DEBUG);
  sendData("AT+COUTGAIN=2", 1000, DEBUG);//from (0-7)
  //sendData("AT+CHUP", 1000, DEBUG);//end the call
#endif
  sendData("AT+CICCID", 1000, DEBUG);
 
   currentTime = millis();
}

void loop() {
 if(millis()-currentTime>50000)
  {
      currentTime = millis();//refresh

     sendData("AT+CHUP", 1000, DEBUG);//end the call
  }
  while (USBSerial.available() > 0) {
    mySerial2.write(USBSerial.read());
    yield();
  }
  while (mySerial2.available() > 0) {
    USBSerial.write(mySerial2.read());
    yield();
  }
}

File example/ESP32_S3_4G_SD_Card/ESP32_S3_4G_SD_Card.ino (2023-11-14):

#include <Arduino.h>

//HardwareSerial mySerial2(2);
#define DEBUG true

#include "FS.h"
#include <SD_MMC.h>
#include "SPI.h"

#define IO_RXD2 47
#define IO_TXD2 48


#define PIN_SD_CMD 11
#define PIN_SD_CLK 12
#define PIN_SD_D0 13

// change this to match your SD shield or module;
// ESP32-S3 4G LTE: pin 10


#define IO_GSM_PWRKEY 4
#define IO_GSM_RST    5

unsigned long currentTime;

void setup()
{
    USBSerial.begin(115200);
    delay(5000);
    SD_MMC.setPins(PIN_SD_CLK, PIN_SD_CMD, PIN_SD_D0);
    // bool begin(const char * mountpoint="/sdcard", bool mode1bit=false, bool format_if_mount_failed=false, int sdmmc_frequency=BOARD_MAX_SDMMC_FREQ, uint8_t maxOpenFiles = 5);
    if (!SD_MMC.begin("/sdcard", true, true))
    {
        USBSerial.println("Card Mount Failed");
        return;
    }
    uint8_t cardType = SD_MMC.cardType();

    if (cardType == CARD_NONE)
    {
        USBSerial.println("No SD_MMC card attached");
        return;
    }

    USBSerial.print("SD_MMC Card Type: ");
    if (cardType == CARD_MMC)
    {
        USBSerial.println("MMC");
    }
    else if (cardType == CARD_SD)
    {
        USBSerial.println("SDSC");
    }
    else if (cardType == CARD_SDHC)
    {
        USBSerial.println("SDHC");
    }
    else
    {
        USBSerial.println("UNKNOWN");
    }

    uint64_t cardSize = SD_MMC.cardSize() / (1024 * 1024);
    USBSerial.printf("SD_MMC Card Size: %lluMB\n", cardSize);

    listDir(SD_MMC, "/", 0);
    listDir(SD_MMC, "/", 2);
    USBSerial.printf("Total space: %lluMB\n", SD_MMC.totalBytes() / (1024 * 1024));
    USBSerial.printf("Used space: %lluMB\n", SD_MMC.usedBytes() / (1024 * 1024));
}

void loop()
{
}

//------------------------------------------------------------------------

void listDir(fs::FS &fs, const char *dirname, uint8_t levels)
{
    USBSerial.printf("Listing directory: %s\n", dirname);

    File root = fs.open(dirname);
    if (!root)
    {
        USBSerial.println("Failed to open directory");
        return;
    }
    if (!root.isDirectory())
    {
        USBSerial.println("Not a directory");
        return;
    }

    File file = root.openNextFile();
    while (file)
    {
        if (file.isDirectory())
        {
            USBSerial.print("  DIR : ");
            USBSerial.println(file.name());
            if (levels)
            {
                listDir(fs, file.path(), levels - 1);
            }
        }
        else
        {
            USBSerial.print("  FILE: ");
            USBSerial.print(file.name());
            USBSerial.print("  SIZE: ");
            USBSerial.println(file.size());
        }
        file = root.openNextFile();
    }
}

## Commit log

2024-02-18 Add schematic of PDF
2024-02-19 Update hardware
    [ESP32-S3 4G LTE CAT1 V1.1.brd, ESP32-S3 4G LTE CAT1 V1.1.sch]
2026-06-12 Add sch and brd
    [ESP32-S3 4G LTE CAT1 V1.2.brd, ESP32-S3 4G LTE CAT1 V1.2.sch]

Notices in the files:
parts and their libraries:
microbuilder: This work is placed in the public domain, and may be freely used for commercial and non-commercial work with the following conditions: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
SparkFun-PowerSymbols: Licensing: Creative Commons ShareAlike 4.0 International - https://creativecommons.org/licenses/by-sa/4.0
